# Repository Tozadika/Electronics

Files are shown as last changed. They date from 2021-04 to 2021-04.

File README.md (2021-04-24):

# PS-DC-3V3-2A

Thank you to read this readme file
It's an simple electronic project.

-----------------------------------------------------
Intro

Simple board for electronic enthousiastic who are looking for compact, and powerfull module to power supply 3.3Vdc logic circuit.
All design is based on the Maxim Integrated MAX17643 synchronous step-down DC-DC Converter with internal compensation.

Basic technical data :

Input voltage : 4.5V to 60 Vdc
Output voltage : 3.3 Vdc
Maximum output current : 2A

-----------------------------------------------------
Specific component for this project

All specifics components are include on Components folder.
To configure kicad to recognize symbol and footprint on start, add a variable : ${PROJ_REPO} : path to your root project folder.

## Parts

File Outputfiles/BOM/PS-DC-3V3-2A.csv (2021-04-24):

Source:,"C:\Users\asus\Documents\Eletronique\PS-DC-3V3-2A\Design\PS-DC-3V3-2A.sch"
Date:,"24/04/2021 13:31:42"
Tool:,"Eeschema (5.1.9)-1"
Generator:,"C:\Program Files\KiCad\bin\scripting\plugins/bom_csv_grouped_by_value.py"
Component Count:,"13"
Item | Qty | Reference(s) | Value | Description | Link | MPN | Manufacturer
1 | 1 | C1 | 5.6n | Condensateur céramique multicouche CMS, 5600 pF, 10 V, 0603 [1608 Metric], ± 5%, X7R | https://fr.farnell.com/kemet/c0603c562j8ractu/condensateur-5600pf-10v-mlcc-0603/dp/2941954 | C0603C562J8RACTU | Kemet
2 | 1 | C2 | 4.7u | Condensateur céramique multicouche CMS, 4.7 µF, 10 V, 0805 [2012 Metric], ± 10%, X7R, Série C | https://fr.farnell.com/tdk/c2012x7r1a475k125ac/condensateur-4-7-f-10v-10-x7r/dp/2346936 | C2012X7R1A475K125AC | TDK
3 | 1 | C3 | 0.1u | Condensateur céramique multicouche CMS, 0.1 µF, 25 V, 0603 [1608 Metric], ± 10%, X8R, GCM Series | https://fr.farnell.com/murata/gcm188r91e104ka37d/cap-aec-q200-0-1uf-25v-mlcc-0603/dp/3581589 | GCM188R91E104KA37D | Murata
4 | 1 | C4 | 47u | Condensateur céramique multicouche CMS, 47 µF, 6.3 V, 1210 [3225 Metric], ± 10%, X7R, GCM Series | https://fr.farnell.com/murata/gcm32er70j476ke19l/condensateur-47-f-6-3v-10-x7r/dp/2688490 | GCM32ER70J476KE19L | Murata
5 | 1 | C5 | 2.2u | Condensateur céramique multicouche CMS, 2.2 µF, 100 V, 1210 [3225 Metric], ± 10%, X7R | https://fr.farnell.com/kemet/c1210c225k1ractu/cond-2-2-f-100v-10-x7r-1210/dp/1793832 | C1210C225K1RACTU | Kemet
6 | 1 | J1 | Conn_01x02 | Bornier fil-à-carte, 2.54 mm, 2 Voies, 30 AWG, 16 AWG, 1.4 mm², Par vis | https://fr.farnell.com/buchanan-te-connectivity/282834-2/terminal-block-pcb-30-16awg-2/dp/2112482 | 282834-2 | TE-Connectivity
7 | 1 | J2 | Conn_01x06 | Header m�le, Carte-�-carte, 2.54 mm, 1 Rang�e(s), 6 Contact(s), Traversant, droit, S�rie 2211S | 2211S-06G Multicomp Pro, Header m�le, Carte-�-carte, 2.54 mm | Farnell FR | 2211S-06G | MULTICOMP PRO
8 | 1 | L1 | 6.8u | Inductance de puissance (CMS), 6.8 µH, 6.4 A, Blindé, 6 A, Série XAL5050, 5.48mm x 5.28mm x 5.1mm | https://fr.farnell.com/coilcraft/xal5050-682mec/inductance-6-8uh-6-4a-20-pwr-21mhz/dp/2289071 | XAL5050-682MEC | Coilcraft
9 | 1 | R1 | 40.2k | Résistance à puce CMS, Couche épaisse, 40.2 kohm, ± 1%, 100 mW, 0603 [1608 Metric], Couche épaisse | https://fr.farnell.com/panasonic/erj3ekf4022v/res-couche-epaisse-40-2k-1-0-1w/dp/2059463 | ERJ3EKF4022V | Panasonic
10 | 1 | R2 | 52.3k | Résistance à puce CMS, Couche mince, 52.3 kohm, ± 0.1%, 100 mW, 0603 [1608 Metric] | https://fr.farnell.com/panasonic/era3arb5232v/res-52-3k-0-1-0-1w-0603-film-metal/dp/2094621 | ERA3ARB5232V | Panasonic
11 | 1 | R3 | 19.6k | Résistance à puce CMS, Couche mince, 19.6 kohm, ± 0.1%, 100 mW, 0603 [1608 Metric] | https://fr.farnell.com/panasonic/era3arb1962v/res-19-6k-0-1-0-1w-0603-film-metal/dp/2094532 | ERA3ARB1962V | Panasonic
12 | 1 | R4 | 10k | Résistance à puce CMS, Couche épaisse, 10 kohm, ± 1%, 100 mW, 0603 [1608 Metric], Couche épaisse | https://fr.farnell.com/panasonic/erj3ekf1002v/res-couche-epaisse-10k-1-0-1w/dp/2303192 | ERJ3EKF1002V | Panasonic
13 | 1 | U1 | MAX17643 | DC/DC POL Converter, Adjustable, Synchronous Buck, 4.5 V to 60 V in, 0.9-54V out, TDFN-EP, 12Pin | https://fr.farnell.com/maxim-integrated-products/max17643atc/conv-dc-dc-sync-buck-2-2mhz-125/dp/3653247 | MAX17643ATC+ | Maxim-Integrated

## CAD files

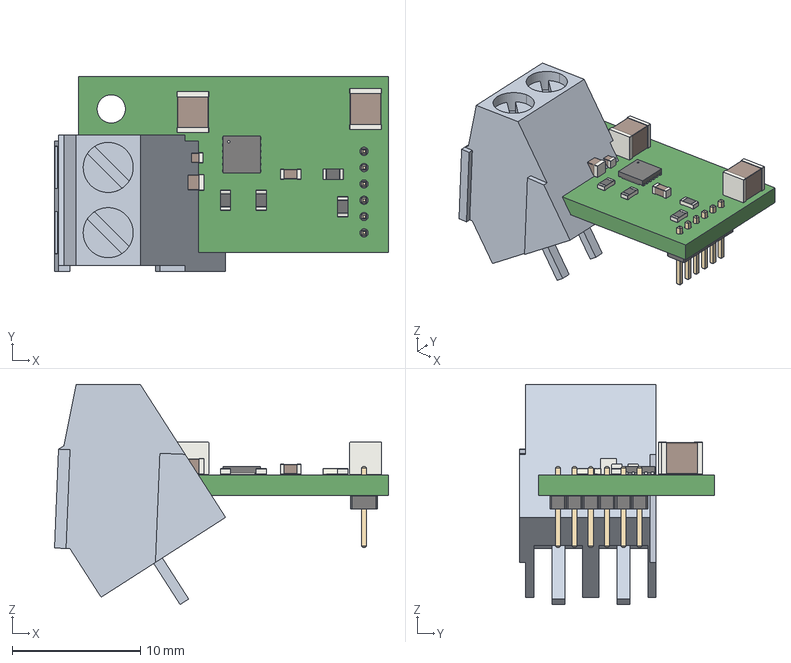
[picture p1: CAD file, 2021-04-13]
Outputfiles/PS-DC-3V3-2A.step
26.0 x 15.2 x 17.1 mm
Coilcraft-XAL5050

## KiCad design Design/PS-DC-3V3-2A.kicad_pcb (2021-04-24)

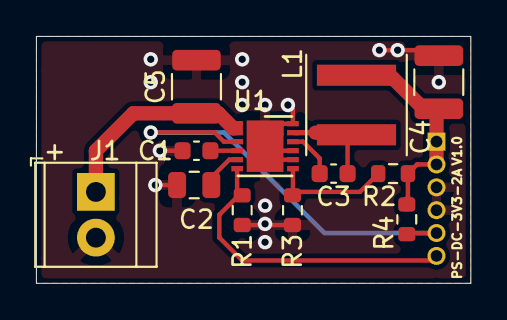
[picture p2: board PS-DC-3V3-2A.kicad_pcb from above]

Board: 2 copper layers, 24.1 x 13.7 mm, 13 parts (1 on the bottom side), 10 nets.

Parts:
C1: 5.6n; C_0603_1608Metric
C2: 4.7u; C_0805_2012Metric
C3: 0.1u; C_0603_1608Metric
C4: 47u; C_1210_3225Metric
C5: 2.2u; C_1210_3225Metric
J1: Conn_01x02; TerminalBlock_TE_282834-2_1x02_P2.54mm_Horizontal
J2: Conn_01x06; PinHeader_1x06_P1.27mm_Vertical
L1: 6.8u; L_Coilcraft_XAL5050-682
R1: 40.2k; R_0603_1608Metric
R2: 52.3k; R_0603_1608Metric
R3: 19.6k; R_0603_1608Metric
R4: 10k; R_0603_1608Metric
U1: MAX17643; DFN-12-1EP_3x3mm_P0.5mm_EP2.05x2.86mm

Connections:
GND: C1.2, C2.2, C4.2, C5.1, J1.2, J2.3, J2.4, R1.2, R3.2, U1.8, U1.9, U1.12, U1.13
unnamed: C1.1, U1.4
unnamed: C2.1, U1.5
unnamed: C3.1, U1.10
unnamed: C3.2, L1.1, U1.11
unnamed: R2.2, R3.1, U1.7
SYNC: J2.6, R1.1, U1.6
Vin: C5.2, J1.1, U1.1, U1.2
Vout: C4.1, J2.1, J2.2, L1.2, R2.1, R4.2
\Reset: J2.5, R4.1, U1.3

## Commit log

2021-04-12 Init repository
    [PS-DC-3V3-2A.kicad_pcb, PS-DC-3V3-2A.sch]
2021-04-12 Init schematic folio
2021-04-12 Create scheamtic
    [PS-DC-3V3-2A.sch]
2021-04-12 Create pcb, draft done, have to clean pcb layers, improve routing, add 3dfiles to libraries
    [PS-DC-3V3-2A.kicad_pcb]
2021-04-12 Change library path with PROJ_REPO variable
    [PS-DC-3V3-2A.kicad_pcb]
2021-04-13 Attach 3d file to CoilCraft
2021-04-13 Add Sync and reset components, re-arange
    [PS-DC-3V3-2A.kicad_pcb]
2021-04-13 Change output conenctor references, add reset and sync pull-down
    [PS-DC-3V3-2A.sch]
2021-04-13 Change Con_1x04 => Con_1x06
    [PS-DC-3V3-2A.kicad_pcb, PS-DC-3V3-2A.sch]
2021-04-13 Add BOM, Drill files, Gerber files, step (have to be adjust), position files
    [PS-DC-3V3-2A-B_Cu.gbr, PS-DC-3V3-2A-B_Mask.gbr, PS-DC-3V3-2A-B_Paste.gbr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]
2021-04-24 Suppress pull-down resistaor on nReset signal, replaced by 10k pull-up
    [PS-DC-3V3-2A.kicad_pcb, PS-DC-3V3-2A.sch]
2021-04-24 Change resistor reference
    [PS-DC-3V3-2A.csv]
2021-04-24 change connector J2 reference
    [PS-DC-3V3-2A.csv]
2021-04-24 Drill file updated
    [PS-DC-3V3-2A-NPTH.drl, PS-DC-3V3-2A-PTH.drl]
2021-04-24 Pull up resistor update
    [PS-DC-3V3-2A-B_Cu.gbr, PS-DC-3V3-2A-B_Mask.gbr, PS-DC-3V3-2A-B_Paste.gbr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]
